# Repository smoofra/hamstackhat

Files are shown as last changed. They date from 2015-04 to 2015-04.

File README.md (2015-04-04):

hamstackHAT
==========

This is a raspberry pi HAT board for interfacing to a
[hamstack Series 200](http://www.hamstack.com/repeatercontroller.html)
repeater controller.

It is compatible with raspberries with the 40 pin header, such as the B+.

The hamstack cpu board has a db25 gpio connector with 8 digital out pins and 8
digital in pins.  These are connected to the 16 general purpose gpio pins on the
pi.  The UART, SPI, and I2C pins are left unused.  The hamstack's analog inputs
are unused.

The pin assignments are:

|Raspberry |Hamstack |
|---|---|
|GPIO26 |DIGITAL IN 13  |
|GPIO19 |DIGITAL IN 12  |
|GPIO13 |DIGITAL IN 24  |
|GPIO6 |DIGITAL IN 11  |
|GPIO5 |DIGITAL IN 23  |
|GPIO22 |DIGITAL IN 10  |
|GPIO27 |DIGITAL IN 22  |
|GPIO17 |DIGITAL IN 9 |
|GPIO18 |DIGITAL OUT 5  |
|GPIO23 |DIGITAL OUT 7  |
|GPIO24 |DIGITAL OUT 6  |
|GPIO25 |DIGITAL OUT 8  |
|GPIO12 |DIGITAL OUT 18 |
|GPIO16 |DIGITAL OUT 19 |
|GPIO20 |DIGITAL OUT 20 |
|GPIO21 |DIGITAL OUT 21 |

The hamstack also has a RS232 control interface.  To interface that just use any
USB to RS232 adapter cable.

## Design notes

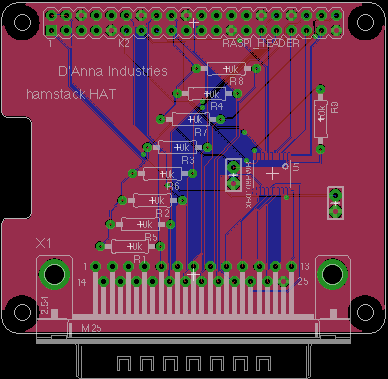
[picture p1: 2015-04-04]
hamstackhat.png

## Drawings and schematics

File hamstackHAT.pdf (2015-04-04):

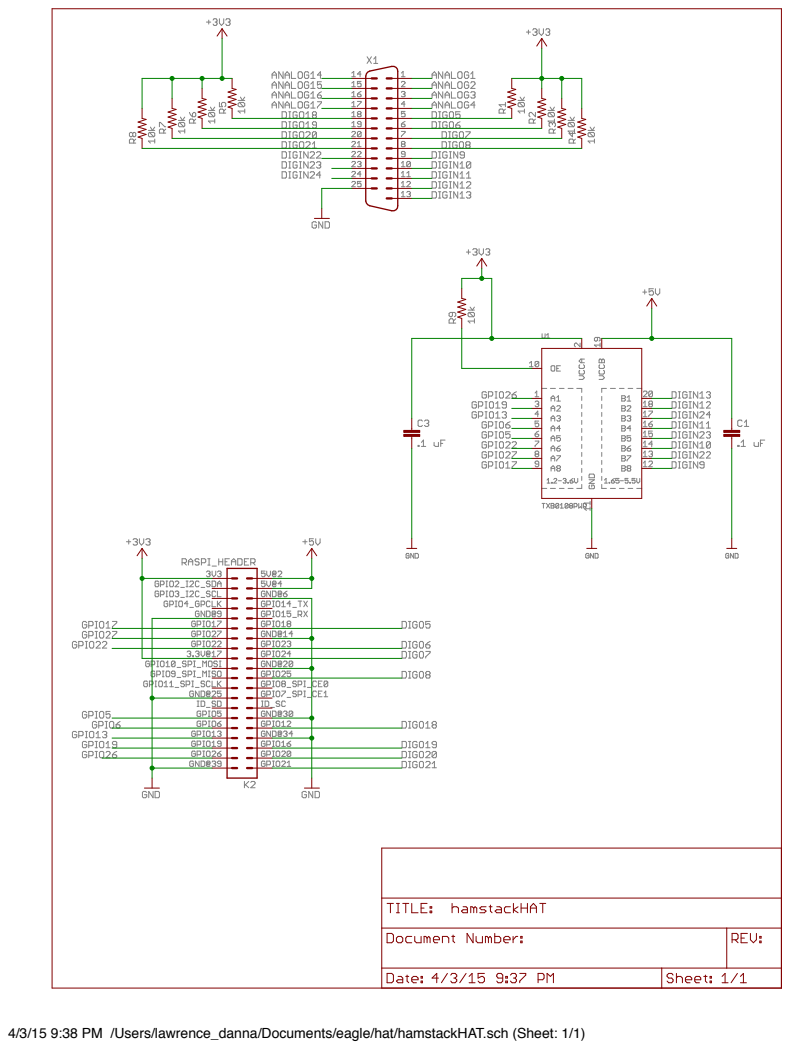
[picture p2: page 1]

4/3/15 9:38 PM /Users/lawrence_danna/Documents/eagle/hat/hamstackHAT.sch (Sheet: 1/1)

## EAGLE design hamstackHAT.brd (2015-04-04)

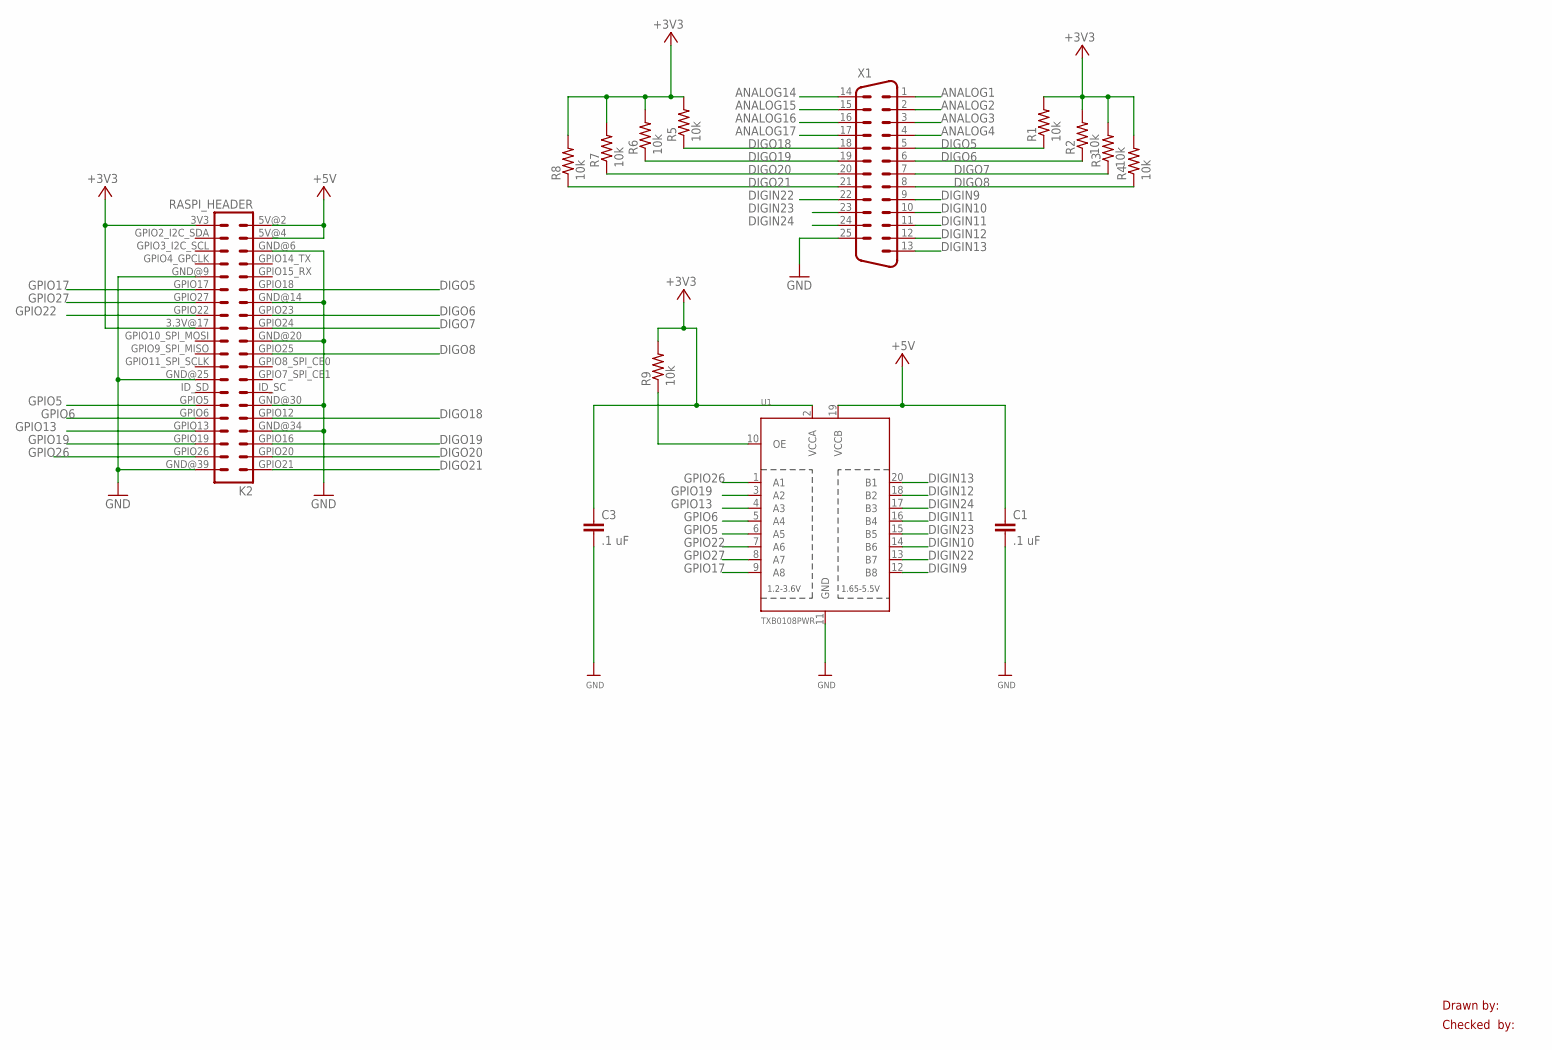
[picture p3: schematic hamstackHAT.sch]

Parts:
C1, C3: .1 uF; CAP-PTH-SMALL-KIT
K2: RASPI_HEADER
R1, R2, R3, R4, R5, R6, R7, R8, R9: 10k; 0207/10
U1: TXB0108PWR; TSSOP20
X1: M25HP

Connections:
+3V3: C3.1, K2.3.3V@17 (17), K2.3V3 (1), R1.2, R2.2, R3.2, R4.2, R5.2, R6.2, R7.2, R8.2, R9.2, U1.2 (VCCA)
+5V: C1.1, K2.5V@2 (2), K2.5V@4 (4), U1.19 (VCCB)
ANALOG1: X1.1
ANALOG2: X1.2
ANALOG3: X1.3
ANALOG4: X1.4
ANALOG14: X1.14
ANALOG15: X1.15
ANALOG16: X1.16
ANALOG17: X1.17
DIGIN9: U1.12 (B8), X1.9
DIGIN10: U1.14 (B6), X1.10
DIGIN11: U1.16 (B4), X1.11
DIGIN12: U1.18 (B2), X1.12
DIGIN13: U1.20 (B1), X1.13
DIGIN22: U1.13 (B7), X1.22
DIGIN23: U1.15 (B5), X1.23
DIGIN24: U1.17 (B3), X1.24
DIGO5: K2.GPIO18 (12), R1.1, X1.5
DIGO6: K2.GPIO23 (16), R2.1, X1.6
DIGO7: K2.GPIO24 (18), R3.1, X1.7
DIGO8: K2.GPIO25 (22), R4.1, X1.8
DIGO18: K2.GPIO12 (32), R5.1, X1.18
DIGO19: K2.GPIO16 (36), R6.1, X1.19
DIGO20: K2.GPIO20 (38), R7.1, X1.20
DIGO21: K2.GPIO21, R8.1, X1.21
GND: C1.2, C3.2, K2.GND@6 (6), K2.GND@9 (9), K2.GND@14 (14), K2.GND@20 (20), K2.GND@25 (25), K2.GND@30 (30), K2.GND@34 (34), K2.GND@39 (39), U1.11 (GND), X1.25
GPIO5: K2.GPIO5 (29), U1.6 (A5)
GPIO6: K2.GPIO6 (31), U1.5 (A4)
GPIO13: K2.GPIO13 (33), U1.4 (A3)
GPIO17: K2.GPIO17 (11), U1.9 (A8)
GPIO19: K2.GPIO19 (35), U1.3 (A2)
GPIO22: K2.GPIO22 (15), U1.7 (A6)
GPIO26: K2.GPIO26 (37), U1.1 (A1)
GPIO27: K2.GPIO27 (13), U1.8 (A7)
unnamed: R9.1, U1.10 (OE)

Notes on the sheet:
Drawn by:
Checked by:

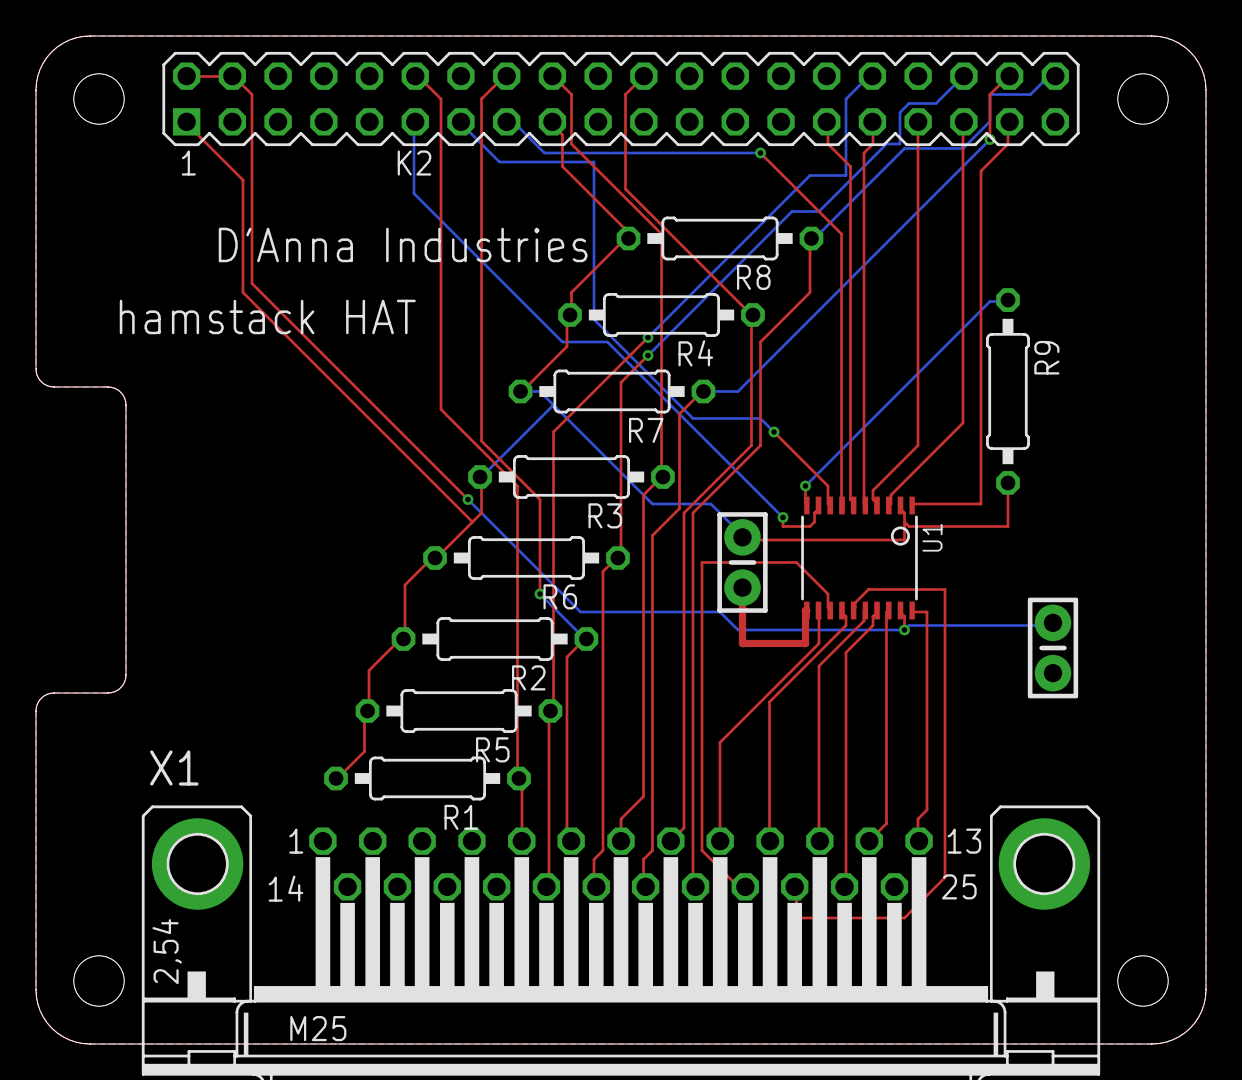
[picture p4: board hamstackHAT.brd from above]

Board: 2 copper layers, 65.0 x 56.0 mm, 14 parts (0 on the bottom side), 28 nets.

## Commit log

2015-04-03 downloaded template from the internet
    [RasPi-BplusHAT.brd, RasPi-BplusHAT.sch]
2015-04-03 imported into project
    [RasPi-BplusHAT.brd, RasPi-BplusHAT.sch]
2015-04-03 add pin labels to raspi header
    [RasPi-BplusHAT.brd]
2015-04-03 add db15 and labeled nets
    [RasPi-BplusHAT.brd, RasPi-BplusHAT.sch]
2015-04-03 add pullups
    [RasPi-BplusHAT.brd, RasPi-BplusHAT.sch]
2015-04-03 hook up digo pins to gpios
    [RasPi-BplusHAT.brd, RasPi-BplusHAT.sch]
2015-04-03 clean up traces
    [RasPi-BplusHAT.brd]
2015-04-03 add level shifter
    [RasPi-BplusHAT.brd, RasPi-BplusHAT.sch]
2015-04-03 add hamstack HAT label
    [RasPi-BplusHAT.brd]
2015-04-03 rename files
    [hamstackHAT.brd, hamstackHAT.sch]
2015-04-04 re-arange everythign to imporove routing
    [hamstackHAT.brd, hamstackHAT.sch]
2015-04-04 pin table
2015-04-04 tidy up schematic for letter paper
    [hamstackHAT.sch]

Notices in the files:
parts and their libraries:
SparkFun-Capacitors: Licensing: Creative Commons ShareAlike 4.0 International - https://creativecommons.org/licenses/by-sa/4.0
